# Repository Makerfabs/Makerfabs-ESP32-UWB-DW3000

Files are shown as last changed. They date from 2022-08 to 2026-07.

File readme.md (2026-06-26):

# Makerfabs ESP32 UWB DW3000

**The DW3000 library in this repository was developed by NConcepts, not Makerfabs.  Makerfabs is simply responsible for maintaining the repository.**

```c++
/*
Version:        V1.2
Author:            Vincent
Create Date:    2022/8/1
Note:
    2023/5/5     V1.2:The routines that can be used are placed in 
                    the example folder separately, with instructions 
                    added.
    2023/3/18    V1.1:Modify the SPI operating frequency in the library.
                      Added software reset to demo.
*/
```

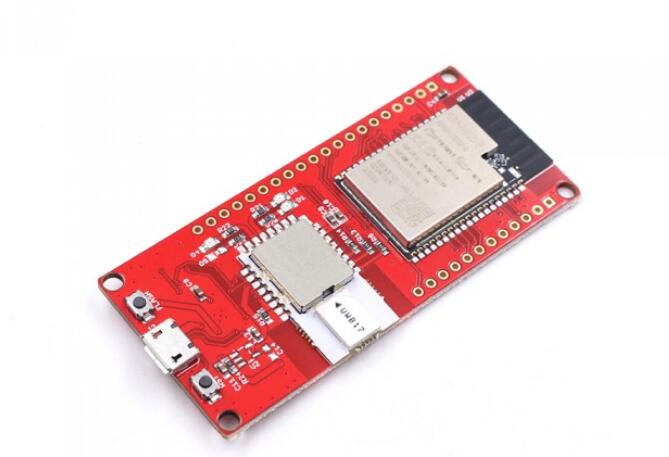
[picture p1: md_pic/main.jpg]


[TOC]

# Makerfabs

[Makerfabs home page](https://www.makerfabs.com/)

[Makerfabs Wiki](https://wiki.makerfabs.com/)

# Makerfabs ESP32 UWB DW3000

## 1.Intruduce

Click the image below to watch the demonstration on YouTube.

Watch the video (https://www.youtube.com/watch?v=JwxK1K1YVI8)

Product Link ：[esp32-uwb-dw3000](https://www.makerfabs.com/esp32-uwb-dw3000.html) 

Wiki Link : [ESP32 UWB DW3000](https://wiki.makerfabs.com/ESP32_DW3000_UWB.html)

Makerfabs ESP32 UWB contains an ESP32 and a DW3000 chip.

Ultra-wideband (UWB) is a short-range, wireless communication protocol that operates through radio waves, enables secure reliable ranging and precision sensing, creating a new dimension of spatial context for wireless devices.

Makerfabs ESP32 UWB module, which is based on IC DecaWave DW1000, has been greatly popular and liked by many Makers. And many customers ask us for the newest DW3000 version, after long-term comparison & testing, now it's available!~

Compares to the DWM1000, the DWM3000 has advantages as below:

1. Most important: Interoperable with Apple U1 chip, that makes it possible to work with the Apple system;
2. Fully aligned with FiRa™ PHY, MAC, and certification development, which make it more suitable for further applications;
3. Much lower Power consumption, almost 1/3 of DWM1000;
4. Supports UWB channels 5 (6.5 GHz) and 9 (8 GHz), while DWM1000 does not support Channel 9;

## 2.Feature

- Integrated ESP32 2.4G WiFi and Bluetooth.
- DW3000 UWB module.

# 3.Usage

ESP32 UWB DW3000 module ranging principle.

ESP32 UWB DW30003.jpg

ESP32 UWB DW30004.jpg

Download the DW3000 library in [GitHub](https://github.com/Makerfabs/Makerfabs-ESP32-UWB-DW3000/tree/main), and put it to the Arduino library file.

**Note: The DW3000 library in this repository was developed by NConcepts, not Makerfabs. Makerfabs is simply responsible for maintaining the repository.**

### 3.1 One Anchor + one Tag

**How to set ESP32 UWB DW3000 module as the anchor port.**

- Prepare the module and connect it to the PC with a USB cable.

- There is a sketch(range_tx.ino) for the setting, the sketch is available on [GitHub](https://github.com/Makerfabs/Makerfabs-ESP32-UWB-DW3000/tree/main). The path is >>example>>range_tx>>range_t.ino.

- Open the sketch with Arduino IDE. If you did not install the ESP32 development board on Arduino IDE, please check here for how to install it.
- Select the development board "ESP32 Dev Module" and the port.

ESP32 UWB DW30005.jpg

- Upload the sketch to the board.

- This module can be an anchor port to receive the other UWB device signal.

**How to use ESP32 UWB DW3000 module to measure the distance from the anchor port.**

How to use ESP32 UWB Pro module to measure the distance from the anchor port.

- Open the sketch **range_rx** by Arduino IDE. The path is >>example>>range_rx>>range_rx.ino
- As above mentioned to install the development board and library.
- Select the development board “ESP32 Dev Module” and the port.
- Upload the sketch to the board.
- Open the serial monitor, it will print the distance from the anchor port.

ESP32 UWB DW30007.jpg

ESP32 UWB DW30006.jpg

### 3.2 Multi Anchor + Multi Tag

This is the example to get the distance and signal strength value from multi Tag to multi Anchor.

The network uses a designated **Master Anchor** to coordinate synchronization and network scheduling.

``` 
#define MASTER_ANCHOR_ID    0xA0
```

The Master Anchor serves as the reference node for the entire UWB network and is responsible for:

- TDMA timing coordination
- Tag scheduling reference
- Maintaining a common network time base

All Anchors and Tags in the network must be configured with the same `MASTER_ANCHOR_ID`.

**Set the board to Anchor X or Tag X**

Open the [Tag](https://github.com/Makerfabs/Makerfabs-ESP32-UWB-DW3000/tree/main/example/Multi%20Anchor%20%2B%20Multi%20Tag/tag) and [Anchor](https://github.com/Makerfabs/Makerfabs-ESP32-UWB-DW3000/tree/main/example/Multi%20Anchor%20%2B%20Multi%20Tag/anchor) by Arduino IDE.

Modify code to get the Anchor or Tag that you want to define

``` 
// 0xA0~0xA7
#define MASTER_ANCHOR_ID    0xA0
```

``` 
//For example 0, 1, 2..
#define TAG_ID              0
```

Use Type-C USB cable to connect the board and PC, and select the development board "ESP32 Dev Module" and the port.

Verify the code and upload.

Repeat to set up multiple Anchor and multiple Tag.



Open the port for any anchor to view the distances from all tags to all anchors.



Results for 8Tag + 8anchor



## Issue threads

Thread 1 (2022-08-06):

Issue with TX example

roncapat, 2022-08-06:
Hello, I tried the code for the Simple TX example.
However, my code stalls in the while loop waiting for TX confirmation (checking TXFRS bit in SYS_STATUS reg). The bit is ever raised.
My SYS_STATUS register is the following:
00001001100000000000000000000111
Could you suggest if there are any other registers to check, particular flags or so?

I know it's not an issue directly related to your product, but your experience reaching production stage of a DWM3000-enabled board may help me a lot. Thank you in advance.

squix78, 2023-03-12:
I'm stuck at the same problem. Did you ever resolve it? I wonder if off-the-shelve DWM3000 are missing OTP calibration values

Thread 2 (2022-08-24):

ranging

c1p81, 2022-08-24:
when will be released the code for ranging tag-anchor (Arduino IDE)?
thanks
L

InfallibleProgrammer, 2022-09-11:
I have the same question

tomasrocchetti, 2023-02-07:
I have the same question, has anyone found a solution?

c1p81, 2023-02-07:
i'm testing this code
https://how2electronics.com/ranging-localization-with-esp32-uwb-dw3000-module/
seems to work...i need to find a way to calibrate the Antenna Delay

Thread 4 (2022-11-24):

Ranging using 9 channels

MitsuyoshiHori, 2022-11-24:
As We mentioned in my e-mail, when We changed the settings from 5ch to 9ch in the following sample, "CONFIG FAILED" due to "PLL LOCKING ERROR" occurred and it did not work properly.

[sample]
Dw3000\examples\ex_06a_ss_twr_initiator\ex_06a_ss_twr_initiator.ino
Dw3000\examples\ex_06b_ss_twr_responder\ex_06b_ss_twr_responder.ino

[Modified part]
static  dwt_config_t config = {
        5 , --（Changes） --> 9 ,

[operation log]
---------------------
Jun  8 2016 00:22:57

rst:0x1 (POWERON_RESET),boot:0x17 (SPI_FAST_FLASH_BOOT)
configsip: 0, SPIWP:0xee
clk_drv:0x00,q_drv:0x00,d_drv:0x00,cs0_drv:0x00,hd_drv:0x00,wp_drv:0x00
mode:DIO, clock div:1
load:0x3fff0030,len:1344
load:0x40078000,len:13864
load:0x40080400,len:3608
entry 0x400805f0
setup() run 9ch...
SS TWR INIT v1.0
DEVICE ID: deca0302
XTRIM OTP READ FAIL
PLL LOCKING ERROR
CONFIG FAILED
---------------------

However, as a result of putting the following serial output in the dw3000_device_api.cpp file, it works even with 9 channels, strangely enough.
We will share this information in the hope of further improvement.

---------------------
    ///////////////////////
    // RF
    if (chan == 9)
    {
        UART_puts("RF ch9 \r\n");   // Add for debug
        // Setup TX analog for ch9
        dwt_write32bitoffsetreg(TX_CTRL_HI_ID, 0, RF_TXCTRL_CH9);
        dwt_write16bitoffsetreg(PLL_CFG_ID, 0, RF_PLL_CFG_CH9);
        // Setup RX analog for ch9
        dwt_write32bitoffsetreg(RX_CTRL_HI_ID, 0, RF_RXCTRL_CH9);
    }
    else
    {
        UART_puts("RF ch5 \r\n");   // Add for debug
        // Setup TX analog for ch5
        dwt_write32bitoffsetreg(TX_CTRL_HI_ID, 0, RF_TXCTRL_CH5);

        dwt_write16bitoffsetreg(PLL_CFG_ID, 0, RF_PLL_CFG_CH5);

    }

    dwt_write8bitoffsetreg(LDO_RLOAD_ID, 1, LDO_RLOAD_VAL_B1);
    dwt_write8bitoffsetreg(TX_CTRL_LO_ID, 2, RF_TXCTRL_LO_B2);

    dwt_write8bitoffsetreg(PLL_CAL_ID, 0, RF_PLL_CFG_LD);        // Extend the lock delay

    //Verify PLL lock bit is cleared
    dwt_write32bitoffsetreg(SYS_STATUS_ID, 0, SYS_STATUS_CP_LOCK_BIT_MASK);

    ///////////////////////
    // auto cal the PLL and change to IDLE_PLL state
    dwt_setdwstate(DWT_DW_IDLE);

    for (flag=1,cnt=0;cnt<MAX_RETRIES_FOR_PLL;cnt++)
    {
       UART_puts("cnt:");         // Add for debug
       Serial.print(cnt, DEC);    // Add for debug
       UART_puts("\r\n");         // Add for debug
       //deca_usleep(DELAY_20uUSec);  /// comment-out
        if ((dwt_read8bitoffsetreg(SYS_STATUS_ID, 0) & SYS_STATUS_CP_LOCK_BIT_MASK))
        {//PLL is locked
      UART_puts("PLL is locked..");
      UART_puts("\r\n");
            flag=0;
            break;
        }
    }
---------------------

GGyul-E, 2024-11-08:
It's because the delay is not enough for PLL locking.
By printing UART Logs, it makes enough delay. So the most easy way is just using while loop for checking `SYS_STATUS_CP_LOCK_BIT_MASK` instead of using for loop.

`
/*for (flag=1,cnt=0;cnt<MAX_RETRIES_FOR_PLL;cnt++)
{
   //UART_puts("cnt:");         // Add for debug
   //Serial.print(cnt, DEC);    // Add for debug
   //UART_puts("\r\n");         // Add for debug
   deca_usleep(DELAY_100uUSec);  /// comment-out
    if ((dwt_read8bitoffsetreg(SYS_STATUS_ID, 0) & SYS_STATUS_CP_LOCK_BIT_MASK))
    {//PLL is locked
  //UART_puts("PLL is locked..");
  //UART_puts("\r\n");
        flag=0;
        break;
    }
}*/

while(dwt_read8bitoffsetreg(SYS_STATUS_ID, 0) & SYS_STATUS_CP_LOCK_BIT_MASK){
        UART_puts("PLL is locked..\r\n");
        flag = 0;
        break;
    }
`

MitsuyoshiHori, 2024-11-10:
Thanks for your comment.
I see, it is due to the lack of delay for the PLL lock.

I will try to find time to check SYS_STATUS_CP_LOCK_BIT_MASK using a while loop instead of a for loop.
As a side note, I have not tried this, but there was some information about another MAX_RETRIES_FOR_PLL setting that I would like to share.

https://forum.qorvo.com/t/esp32-uwb-dw3000-configuration-fails-for-ch9/12789

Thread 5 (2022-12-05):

Ranging Example

Harveyko, 2022-12-05:
Hello, sorry I am very new to this. I just got two https://www.makerfabs.com/esp32-uwb-dw3000.html from makerfabs. I try to use the example code provided on https://github.com/Makerfabs/Makerfabs-ESP32-UWB-DW3000 where I upload the initiator and responder code. I am confused on if the initiator is the anchor or tag, or which one should I kept stationary and which one should I move? Also may I ask is there any example on Antenna Delay Calibration, I found some resources for dw1000 but not dw3000. Thank you!

ThomasLengeling, 2022-12-07:
I have the same question, did you find a way to use the anchor-tags thanks!?

Harveyko, 2022-12-08:
Unfortunately not

vladvlasov256, 2023-04-03:
I had to fix the [example](https://how2electronics.com/ranging-localization-with-esp32-uwb-dw3000-module/) to make it work.

Tag:
```
#define POLL_TX_TO_RESP_RX_DLY_UUS 1720
#define RESP_RX_TIMEOUT_UUS 250
```

Anchor:
```
#define POLL_RX_TO_RESP_TX_DLY_UUS 2000
```

I used the constants from the AES examples [[1]](https://github.com/Makerfabs/Makerfabs-ESP32-UWB-DW3000/blob/3ea4cb14e4429012ae784a3543e146187acd3e09/Dw3000/examples/ex_06e_AES_ss_twr_initiator/ex_06e_AES_ss_twr_i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) and [[2]](https://github.com/Makerfabs/Makerfabs-ESP32-UWB-DW3000/blob/3ea4cb14e4429012ae784a3543e146187acd3e09/Dw3000/examples/ex_06f_AES_ss_twr_responder/ex_06f_AES_ss_twr_r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).

JerryIeong, 2023-04-04:
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

Thank you so much for your help! It works after correcting the values you mentioned!

Basically, what I did for DW3000 ESP32
1. I used "06a_ss_twr_initator" and "06a_ss_twr_responder"
2. change the related values of tag mentioned by Mr. vladvlasov256 (1720 and 250)
3. 2. change the related values of anchor mentioned by Mr. vladvlasov256 (2000)
4. Other content stays the same
5. Then it works

Again! Thank you for your helps!!

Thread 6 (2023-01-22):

UWB with Apple's Nearby Interaction example

Maxakipust, 2023-01-22:
I would love to see an example of Apple's Nearby Interaction working with one of these. Or having one interact with an air tag. Would this be possible?

zeevgrim, 2023-02-08:
+1

MaxIsMyName, 2023-03-09:
@Makerfabs , are you able to ask Qorvo or to port their libdwt_uwb_driver to allow the board to be used, as described on the product page, to interact with Apple's U1 chip?

goku-ks, 2023-04-25:
@Makerfabs, Unfortunately, the esp32 dw3000 is not compatible with this U1 chip if it is not possible to make it work with Apple devices. the claim that it is compatible with U1 chips is wrong.

it I only the Qorvo chip that is compatible with Apple U1 chips, but when it is combined with esp32, it is no more compatible with Apple U1 chips.

goku-ks, 2023-05-20:
@doublebyte , I had the same experience as @MaxIsMyName explained. This is a untrue claim by @Makerfabs that the board is compatible with U1 chips. May be the chip from Qorvo is, but in combination with ESP32 it is not as of now.

BhargavVadaliya, 2023-06-20:
@MaxIsMyName Do you have any news or information regarding the release date of Qorvo's SDK or Firmware for Xtensa chips?

robogrow, 2023-07-02:
Does anyone want to write some NI code for the ESP32?

We might be able to come up with some funding for it.

ivnlabs, 2023-07-02:
@robogrow, I want to write code for the ESP32 DW3000 well-documented code, making the DW3000 TAG connects with more than one ANCHORS and give a correct measurement between all the connected anchors, Does this count?

scinfu, 2023-12-24:
+1

maa-x, 2023-12-25:
For a much cheaper and better product, you can buy Qorvo's DMW3001CDK. It doesn't have WiFi, but you can just make the CDK sent updates over UART and connect an ESP to that.

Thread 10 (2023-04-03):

Double sided two-way ranging

JakobOvergaard, 2023-04-03:
Hi,
I'm currently doing my master thesis in computer science and I'm trying to create a system to test the accuracy of UWB ranging. \
I'm trying to perform double sided two-way ranging using the ESP32 Dw3000 from [makerfabs](https://www.makerfabs.com/esp32-uwb-dw3000.html). - Eventually the goal is to perform asymmetric DB TWR with multiple anchors. \
The code base is written in c++ inspired by QORVOS own example [code](https://www.qorvo.com/products/d/da007992) 'ds_twr_responder' and 'ds_twr_initiator'. \
I'm using the Arduino IDE and this library.

However I'm having some issues with the code, as the final message from the initator to the responder gives me an error, which I cannot decode.
When the responder polls for the final message it reads the system status register for errors, which includes checking the following subregisters: \

All RX error masks:

- SYS_STATUS_RXPHE
- SYS_STATUS_RXFCE
- SYS_STATUS_RXFSL
- SYS_STATUS_RXSTO
- SYS_STATUS_ARFE
- SYS_STATUS_CIAERR

User defined RX error masks:

- SYS_STATUS_RXFTO_BIT_MASK
- SYS_STATUS_RXPTO_BIT_MASK

and the RXFCG subregister.

Printing the system status register gives me the following output:
"131312" which is the decimal representation of the hex value 200F0 and the binary representation of 100000000011110000. \
I know it should be possible to decode which subregister the error is coming from, however I have a hard time figuring it out.\

The code for the intiator and responder is attached below.

Does anyone have any idea what the error could be and how to fix it?

Additionally, I'm very interested in getting in contact with anybody having experience with the ESP32 Dw3000 from makerfabs.

---

Initator code:

```c++
#include "dw3000.h"

#define APP_NAME "SS TWR INIT v1.0"

// connection pins
const uint8_t PIN_RST = 27; // reset pin
const uint8_t PIN_IRQ = 34; // irq pin
const uint8_t PIN_SS = 4;   // spi select pin

/* Default communication configuration. We use default non-STS DW mode. */
static dwt_config_t config = {
    5,                /* Channel number. */
    DWT_PLEN_128,     /* Preamble length. Used in TX only. */
    DWT_PAC8,         /* Preamble acquisition chunk size. Used in RX only. */
    9,                /* TX preamble code. Used in TX only. */
    9,                /* RX preamble code. Used in RX only. */
    1,                /* 0 to use standard 8 symbol SFD, 1 to use non-standard 8 symbol, 2 for non-standard 16 symbol SFD and 3 for 4z 8 symbol SDF type */
    DWT_BR_6M8,       /* Data rate. */
    DWT_PHRMODE_STD,  /* PHY header mode. */
    DWT_PHRRATE_STD,  /* PHY header rate. */
    (129 + 8 - 8),    /* SFD timeout (preamble length + 1 + SFD length - PAC size). Used in RX only. */
    DWT_STS_MODE_OFF, /* STS disabled */
    DWT_STS_LEN_64,   /* STS length see allowed values in Enum dwt_sts_lengths_e */
    DWT_PDOA_M0       /* PDOA mode off */
};

/* Inter-ranging delay period, in milliseconds. */
#define RNG_DELAY_MS 1000

/* Default antenna delay values for 64 MHz PRF. See NOTE 2 below. */
#define TX_ANT_DLY 16385
#define RX_ANT_DLY 16385

/* Frames used in the ranging process. See NOTE 3 below. */
static uint8_t tx_poll_msg[] = {0x41, 0x88, 0, 0xCA, 0xDE, 'C', 'C', 'D', 'D', 0x21, 0, 0};
static uint8_t rx_resp_msg[] = {0x41, 0x88, 0, 0xCA, 0xDE, 'D', 'D', 'C', 'C', 0x10, 0x02, 0, 0};
static uint8_t tx_final_msg[] = {0x41, 0x88, 0, 0xCA, 0xDE, 'C', 'C', 'D', 'D', 0x23, 0, 0, 0, 0, 0, 0, 0, 0, 0, 0, 0, 0, 0, 0};

/* Length of the common part of the message (up to and including the function code, see NOTE 3 below). */
#define ALL_MSG_COMMON_LEN 10
/* Indexes to access some of the fields in the frames defined above. */
#define ALL_MSG_SN_IDX 2
#define RESP_MSG_POLL_RX_TS_IDX 10
#define RESP_MSG_RESP_TX_TS_IDX 14
#define POLL_MSG_POLL_TX_TS_IDX 10

#define FINAL_MSG_POLL_TX_TS_IDX 10
#define FINAL_MSG_RESP_RX_TS_IDX 14
#define FINAL_MSG_FINAL_TX_TS_IDX 18

#define RESP_MSG_TS_LEN 4
/* Frame sequence number, incremented after each transmission. */
static uint8_t frame_seq_nb = 0;

/* Buffer to store received response message.
 * Its size is adjusted to longest frame that this example code is supposed to handle. */
#define RX_BUF_LEN 25
static uint8_t rx_buffer[RX_BUF_LEN];

/* Hold copy of status register state here for reference so that it can be examined at a debug breakpoint. */
static uint32_t status_reg = 0;
static uint32_t poll_tx_ts, resp_rx_ts;

/* Delay between frames, in UWB microseconds. See NOTE 1 below. */
#ifdef RPI_BUILD
#define POLL_TX_TO_RESP_RX_DLY_UUS 240
#endif // RPI_BUILD
#ifdef STM32F429xx
#define POLL_TX_TO_RESP_RX_DLY_UUS 240
#endif // STM32F429xx
#ifdef NRF52840_XXAA
#define POLL_TX_TO_RESP_RX_DLY_UUS 240
#endif // NRF52840_XXAA
/* Receive response timeout. See NOTE 5 below. */
#ifdef RPI_BUILD
#define RESP_RX_TIMEOUT_UUS 270
#endif // RPI_BUILD
#ifdef STM32F429xx
#define RESP_RX_TIMEOUT_UUS 210
#endif // STM32F429xx
#ifdef NRF52840_XXAA
#define RESP_RX_TIMEOUT_UUS 400
#endif // NRF52840_XXAA

#define POLL_TX_TO_RESP_RX_DLY_UUS 240
#define RESP_RX_TO_FINAL_TX_DLY_UUS 300
#define RESP_RX_TIMEOUT_UUS 400

/* Hold copies of computed time of flight and distance here for reference so that it can be examined at a debug breakpoint. */
static double tof, t_round_1, t_reply;
static double distance;

/* Values for the PG_DELAY and TX_POWER registers reflect the bandwidth and power of the spectrum at the current
 * temperature. These values can be calibrated prior to taking reference measurements. See NOTE 2 below. */
extern dwt_txconfig_t txconfig_options;

void setup()
{
  UART_init();
  test_run_info((unsigned char *)APP_NAME);
  Serial.begin(115200);

  /* Configure SPI rate, DW3000 supports up to 38 MHz */
  /* Reset DW IC */
  spiBegin(PIN_IRQ, PIN_RST);
  spiSelect(PIN_SS);

  delay(2); // Time needed for DW3000 to start up (transition from INIT_RC to IDLE_RC, or could wait for SPIRDY event)

  while (!dwt_checkidlerc()) // Need to make sure DW IC is in IDLE_RC before proceeding
  {
    UART_puts("IDLE FAILED\r\n");
    while (1)
      ;
  }

  if (dwt_initialise(DWT_DW_INIT) == DWT_ERROR)
  {
    UART_puts("INIT FAILED\r\n");
    while (1)
      ;
  }

  // Enabling LEDs here for debug so that for each TX the D1 LED will flash on DW3000 red eval-shield boards.
  dwt_setleds(DWT_LEDS_ENABLE | DWT_LEDS_INIT_BLINK);

  /* Configure DW IC. See NOTE 6 below. */
  if (dwt_configure(&config)) // if the dwt_configure returns DWT_ERROR either the PLL or RX calibration has failed the host should reset the device
  {
    UART_puts("CONFIG FAILED\r\n");
    while (1)
      ;
  }

  /* Configure the TX spectrum parameters (power, PG delay and PG count) */
  dwt_configuretxrf(&txconfig_options);

  /* Apply default antenna delay value. See NOTE 2 below. */
  dwt_setrxantennadelay(RX_ANT_DLY);
  dwt_settxantennadelay(TX_ANT_DLY);

  /* Set expected response's delay and timeout. See NOTE 1 and 5 below.
   * As this example only handles one incoming frame with always the same delay and timeout, those values can be set here once for all. */
  dwt_setrxaftertxdelay(POLL_TX_TO_RESP_RX_DLY_UUS);
  dwt_setrxtimeout(RESP_RX_TIMEOUT_UUS);

  /* Next can enable TX/RX states output on GPIOs 5 and 6 to help debug, and also TX/RX LEDs
   * Note, in real low power applications the LEDs should not be used. */
  dwt_setlnapamode(DWT_LNA_ENABLE | DWT_PA_ENABLE);
}

void loop()
{

  tx_poll_msg[ALL_MSG_SN_IDX] = frame_seq_nb;

  dwt_write32bitreg(SYS_STATUS_ID, SYS_STATUS_TXFRS_BIT_MASK);
  dwt_writetxdata(sizeof(tx_poll_msg), tx_poll_msg, 0); /* Zero offset in TX buffer. */
  dwt_writetxfctrl(sizeof(tx_poll_msg), 0, 1);          /* Zero offset in TX buffer, ranging. */

  /* Start transmission, indicating that a response is expected so that reception is enabled automatically after the frame is sent and the delay
   * set by dwt_setrxaftertxdelay() has elapsed. */
  dwt_starttx(DWT_START_TX_IMMEDIATE | DWT_RESPONSE_EXPECTED);

  /* We assume that the transmission is achieved correctly, poll for reception of a frame or error/timeout. See NOTE 8 below. */
  while (!((status_reg = dwt_read32bitreg(SYS_STATUS_ID)) & (SYS_STATUS_RXFCG_BIT_MASK | SYS_STATUS_ALL_RX_TO | SYS_STATUS_ALL_RX_ERR)))
  {
  };

  /* Increment frame sequence number after transmission of the poll message (modulo 256). */
  frame_seq_nb++;

  if (status_reg & SYS_STATUS_RXFCG_BIT_MASK)
  {
    uint32_t frame_len;

    /* Clear good RX frame event & TX frame sent in the DW IC status register. */
    dwt_write32bitreg(SYS_STATUS_ID, SYS_STATUS_RXFCG_BIT_MASK);
    dwt_write32bitreg(SYS_STATUS_ID, SYS_STATUS_TXFRS_BIT_MASK);

    /* A frame has been received, read it into the local buffer. */
    frame_len = dwt_read32bitreg(RX_FINFO_ID) & RXFLEN_MASK;
    if (frame_len <= sizeof(rx_buffer))
    {
      dwt_readrxdata(rx_buffer, frame_len, 0);
    }

    /* Check that the frame is the expected response from the companion "SS TWR responder" example.
     * As the sequence number field of the frame is not relevant, it is cleared to simplify the validation of the frame. */
    rx_buffer[ALL_MSG_SN_IDX] = 0;
    if (memcmp(rx_buffer, rx_resp_msg, ALL_MSG_COMMON_LEN) == 0)
    {

      uint32_t final_tx_ts, final_tx_time;
      int ret;
      float clockOffsetRatio;

      /* Retrieve poll transmission and response reception timestamps. See NOTE 9 below. */
      poll_tx_ts = dwt_readtxtimestamplo32();
      resp_rx_ts = dwt_readrxtimestamplo32();

      /* Read carrier integrator value and calculate clock offset ratio. See NOTE 11 below. */
      clockOffsetRatio = ((float)dwt_readclockoffset()) / (uint32_t)(1 << 26);

      /* Compute final message transmission time. See NOTE 7 below. */
      final_tx_time = (resp_rx_ts + (RESP_RX_TO_FINAL_TX_DLY_UUS * UUS_TO_DWT_TIME)) >> 8;
      dwt_setdelayedtrxtime(final_tx_time);

      /* final TX timestamp is the transmission time we programmed plus the antenna delay. */
      final_tx_ts = (((uint64_t)(final_tx_time & 0xFFFFFFFEUL)) << 8) + TX_ANT_DLY;

      /* Write resp_rx_ts & final_tx_ts in the final message. See NOTE 8 below. */
      final_msg_set_ts(&tx_final_msg[FINAL_MSG_POLL_TX_TS_IDX], poll_tx_ts);
      final_msg_set_ts(&tx_final_msg[FINAL_MSG_RESP_RX_TS_IDX], resp_rx_ts);
      final_msg_set_ts(&tx_final_msg[FINAL_MSG_FINAL_TX_TS_IDX], final_tx_ts);

      /* Write and send the response message. See NOTE 9 below. */
      tx_final_msg[ALL_MSG_SN_IDX] = frame_seq_nb;
      dwt_writetxdata(sizeof(tx_final_msg), tx_final_msg, 0); /* Zero offset in TX buffer. */
      dwt_writetxfctrl(sizeof(tx_final_msg), 0, 1);           /* Zero offset in TX buffer, ranging. */
      ret = dwt_starttx(DWT_START_TX_DELAYED);

      if (ret == DWT_SUCCESS)
      {
        test_run_info((unsigned char *)"Succes");
        /* Poll DW IC until TX frame sent event set. See NOTE 6 below. */
        while (!(dwt_read32bitreg(SYS_STATUS_ID) & SYS_STATUS_TXFRS_BIT_MASK))
        {
        };
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
MaxIsMyName, 2023-04-03:
You should probably read the DW3000’s datasheet.

lordxxbyron, 2023-04-12:
I am also interested in collaborating with a double sided two way ranging - you can PM me at lordxxbyron@gmail.com

Gurkengewuerz, 2024-01-17:
Hey @JakobOvergaard and @lordxxbyron did you ever succeeded with a working example?

JakobOvergaard, 2024-02-29:
@Gurkengewuerz Unfortunately not. I ended up doing singled sided two way ranging from one target to multiple anchors, which worked decently, however it had troubles estimating the position of fast moving targets accurately.

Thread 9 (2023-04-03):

The ESP32 DW3000 Pair is unable to Connect

JerryIeong, 2023-04-03:
Hi,

Let me thank in advance.

I am trying to connect two ESP32 DW3000 and to show the distance between two by using the sample code in arduino "ex_06a_ss_twr_initiator" and "ex_06a_ss_twr_responder".

However, the connection is not successful, once I embedded the programmes into the baords and open the serial monitor to see the result, the program just showed

- SS TWR INIT v1.0
- DEVICE ID: deca0302
- XTRIM OTP READ FAIL
- PLL is locked..
- PGF cal complete..

(The board name I used is ESP32 Wrover Modulus)

Did I miss something and can anyone help me out with this?

Thank you for your helps!

vladvlasov256, 2023-04-03:
@JerryIeong maybe this answer helps:
https://github.com/Makerfabs/Makerfabs-ESP32-UWB-DW3000/issues/5#issuecomment-1493962519

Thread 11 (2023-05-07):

Putting ESP32 DW3000 Pair into Sleep

JerryIeong, 2023-05-07:
Hi,

Let me thank in advance.

I have been working on DW3000 distance detection and warning system for few months and everything works fine, when the two UWB systems get too close, a pin will be triggered to activate an alarm.

I am currently using the "ex_06a_ss_twr_initator" and "ex_06a_ss_twr_responder" with Arduino for the system.

 After certain period of testing, I realized that the power consumption is quite high which may not be suitable for the system to be portable by carrying batteries. After reading through the manuals, I found out that there are different modes, like "sleep", "deep sleep" and "sniff mode", and there are also two "sleep" example programming in the Arduino.

Could anyone please instruct me how I can add these modes into my Arduino program for reducing power consumption?

Thank you for your helps!

MaxIsMyName, 2023-05-07:
You would have to read the datasheet for the DW3000 and send the correct command to enter and exit sleep or deep sleep.

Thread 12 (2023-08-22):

LEDSFD pin

LowellSeal, 2023-08-22:
Is there a way to make the LEDSFD pin go high to light LED D4 when a Start of Frame is Detected?  I don't see anything in the driver to do that but if someone has figured it out I'd sure appreciate knowing about it.

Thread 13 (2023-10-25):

When setting interrupts - i get an IllegalInstruction exception

ChristofGroschke, 2023-10-25:
Hi there,

I am currently using the dw3000 for a small university project. I am having a lot of problems enabling interrupts. One of them is that I can't call dwt_setInterrupts without the system rebooting due to an illegal instruction. I found out that the decamutexon function defined in dw3000_mutex.cpp should return a value, but it doesn't. The compiler warns me about this, but normally this shouldn't be a problem. If I return a value like NULL, the compilation is successful. Interrupts still don't work, but I'm not sure if that's related to this problem.

I have tried Ubuntu 22.04 with Arduino 1.8.19 and Windows 11 with Arduino 1.8.19 & 2.2.1 and neither works. Can anyone enlighten me on this?

Thanks in advance.

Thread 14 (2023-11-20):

How to set up the driver correctly for device ID DECA0314(DW3120)

AM0219350, 2023-11-20:
Hello,
I was implemented the TWR case with DWM3000 module. Now, I want to do the same thing on the ic DW3120 with single channel(one antenna) first. There are my problems below:

1. Is dw3000 api work on dw3120? The device id of dw3120 is deca0314. In the dw3000_device_api.h. Supported device are deca0302 and deca0312.
2. When I bypass the ckeck of device ID. I got failed in the procedure dwt_configure.
Check procedures:
---1. dwt_checkidlerc()
---2. dwt_initialise(DWT_DW_INIT) == DWT_ERROR
------ in the end of step 2. I got message "XTRIM OTP READ FAIL"
---3. dwt_configure(&config)
---4. Complete the above steps. ESP32 collapse.
3. How to set the dw3120 to use only one antenna?

Thanks,
Ken.

Screen shots:
1. ESP IDF
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
2. XIRIM OTP READ FAIL
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
3. Device IDs of the library(2013-2020)
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
4. Qorvo download library(2013-2021) new
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

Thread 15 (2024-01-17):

INIT FAILED

scinfu, 2024-01-17:
I have this problem with  example codes.
Anyone know why?
i'm using MaUWB_DW3000 with STM32 AT Command
SKU MAUWBCA1
https://www.makerfabs.com/mauwb-dw3000-with-stm32-at-command.html

```
....
12:35:25.674 -> [  1398][V][esp32-hal-periman.c:229] perimanSetBusDeinit(): Deinit function for type GPIO (1) successfully set to 0x400f52e8
12:35:25.674 -> [  1409][V][esp32-hal-periman.c:154] perimanSetPinBus(): Pin 4 successfully set to type GPIO (1) with bus 0x5
12:35:25.705 -> [  1423][V][esp32-hal-periman.c:229] perimanSetBusDeinit(): Deinit function for type GPIO (1) successfully set to 0x400f52e8
12:35:25.705 -> [  1434][V][esp32-hal-periman.c:154] perimanSetPinBus(): Pin 27 successfully set to type GPIO (1) with bus 0x1c
12:35:25.739 -> DEVICE ID: ffffffff

12:35:25.739 -> INIT FAILED
```

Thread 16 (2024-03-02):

MISO and MOSI are swapped

spectrachrome, 2024-03-02:
Running voltage measured on the DW3000 is ~2V until the two pins are swapped, then all SPI ports run 3.3V.

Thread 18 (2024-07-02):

XTRIM OTP READ FAIL

El-len000, 2024-07-02:
I tried the examples for the responder and initiator (e.g., ex_06b_ss_twr_responder_sts and ex_06e_AES_ss_twr_initiator), but I get the following error message:

XTRIM OTP READ FAIL

PLL is locked..
PGF cal complete..

I am new to using this device. I would really appreciate your help on how to resolve this error.

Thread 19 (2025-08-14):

Channel 9 not working

adijams01, 2025-08-14:
I am trying to use channel 9,  leds are not blinking and there is no output on the receiver's end of the serial print,
Can you please provide an example script for rx and tx using channel 9?
Thank you!

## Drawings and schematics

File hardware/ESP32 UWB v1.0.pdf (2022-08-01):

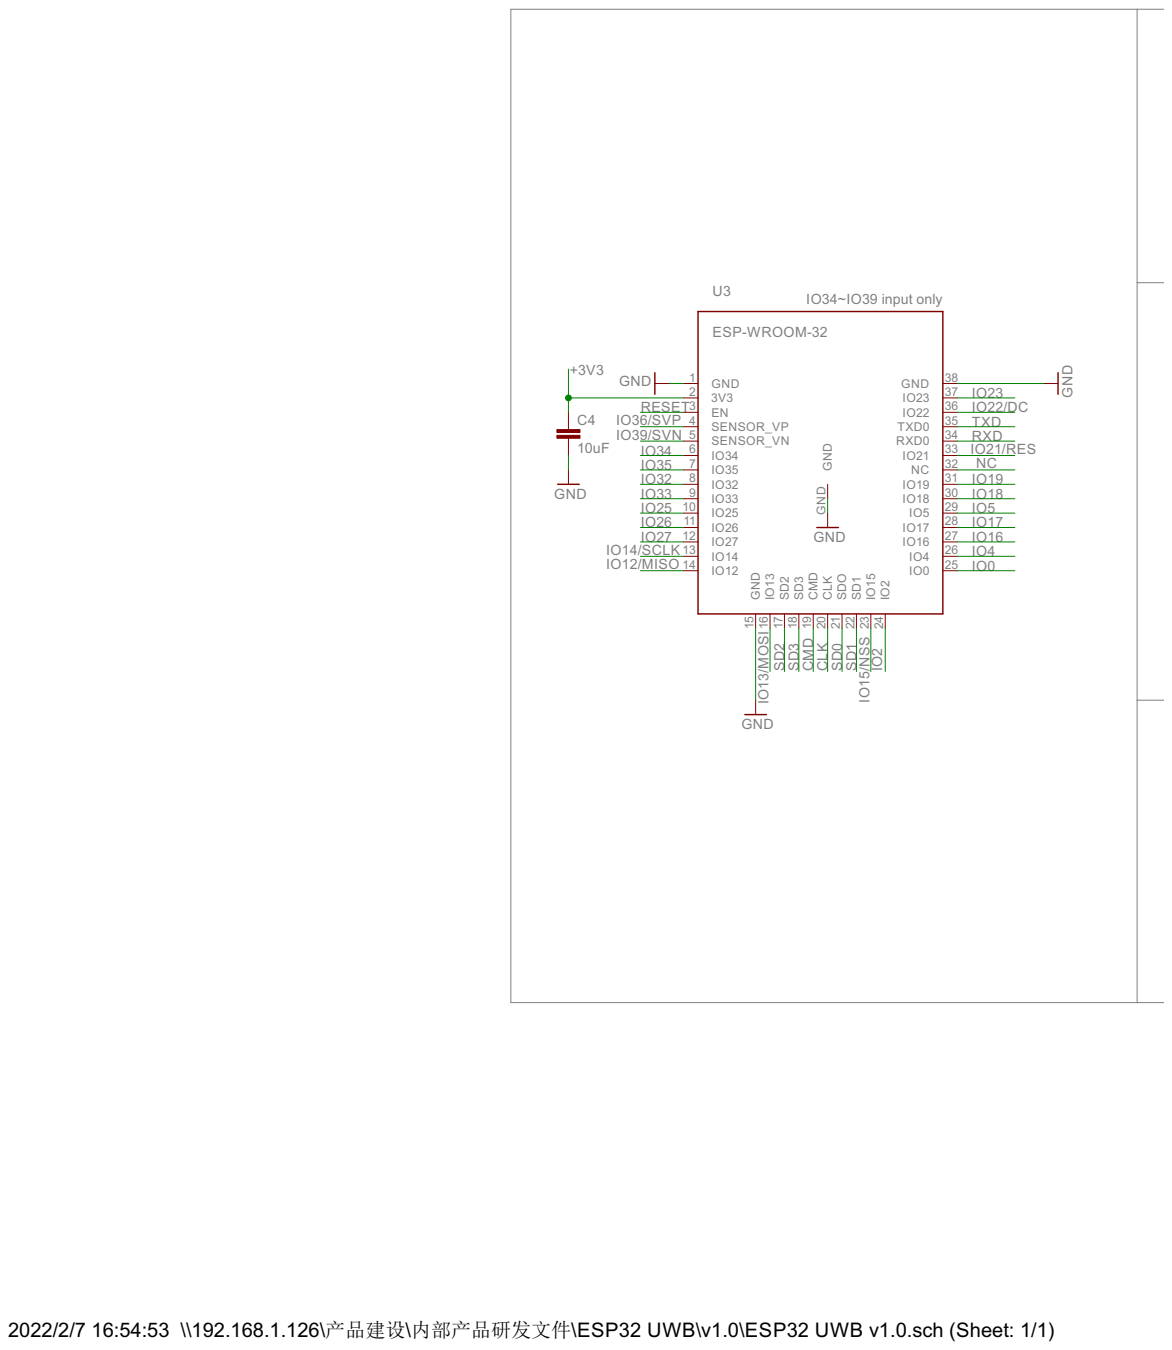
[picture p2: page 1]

2022/2/7 16:54:53 \\192.168.1.126\产品建设\内部产品研发文件\ESP32 UWB\v1.0\ESP32 UWB v1.0.sch (Sheet: 1/1)

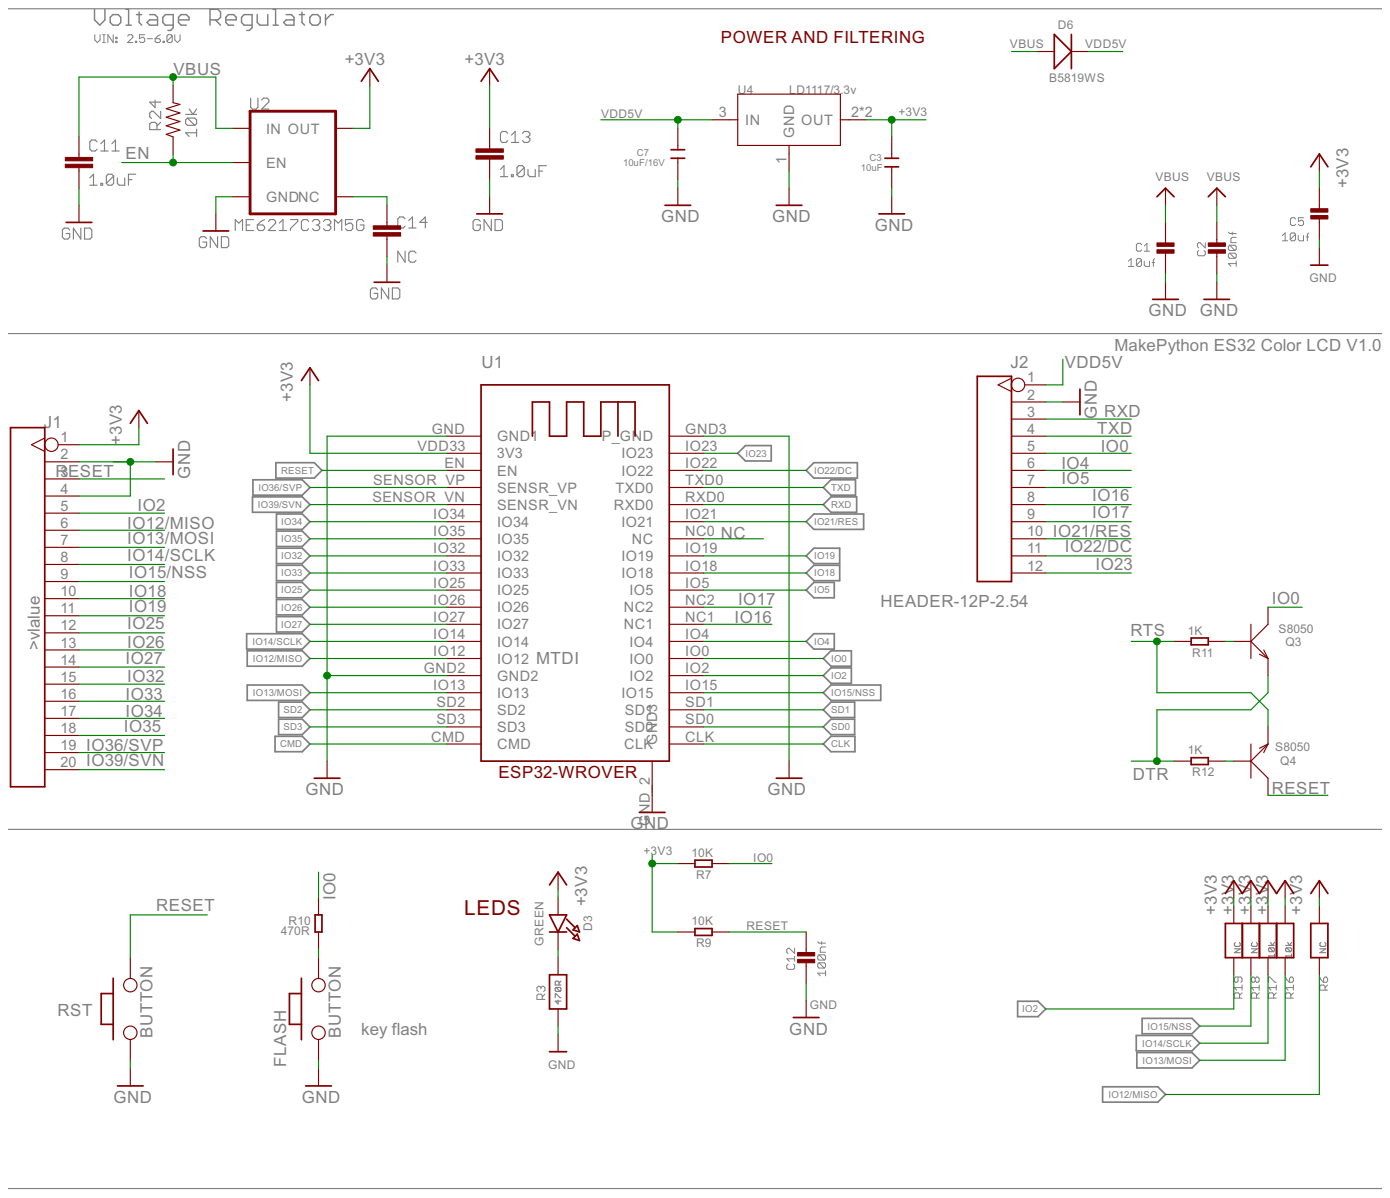
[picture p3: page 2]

IO25 | IO5
IO26 | IO17
IO27 | IO4 NC1 NC1 NC2 NC2 IO16

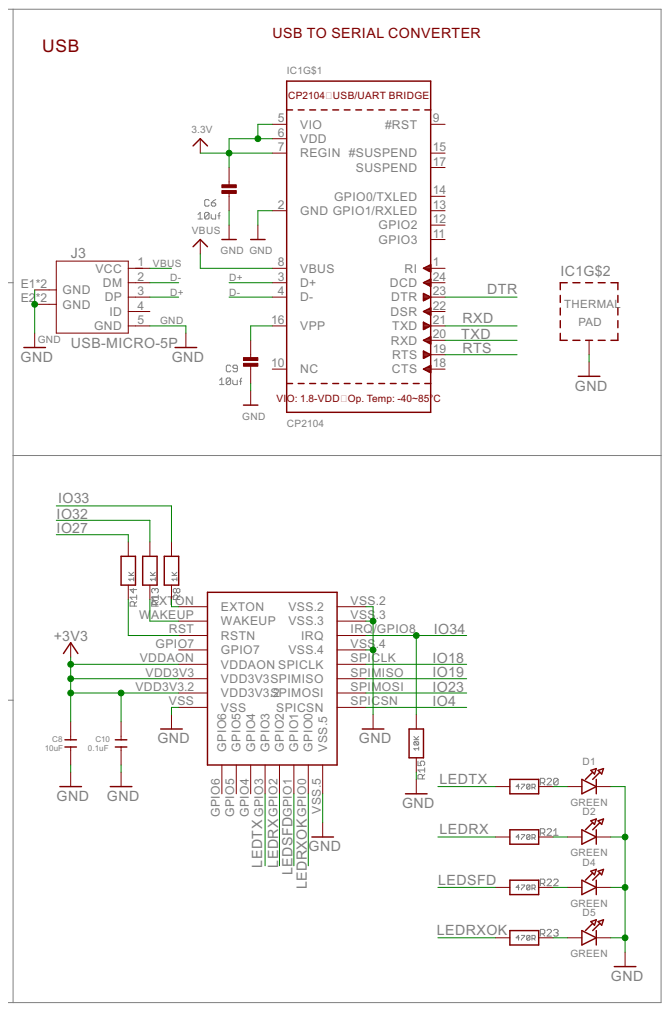
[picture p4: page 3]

USB TO SERIAL CONVERTER

VIO: 1.8-VDDOp. Temp: -40~85°C

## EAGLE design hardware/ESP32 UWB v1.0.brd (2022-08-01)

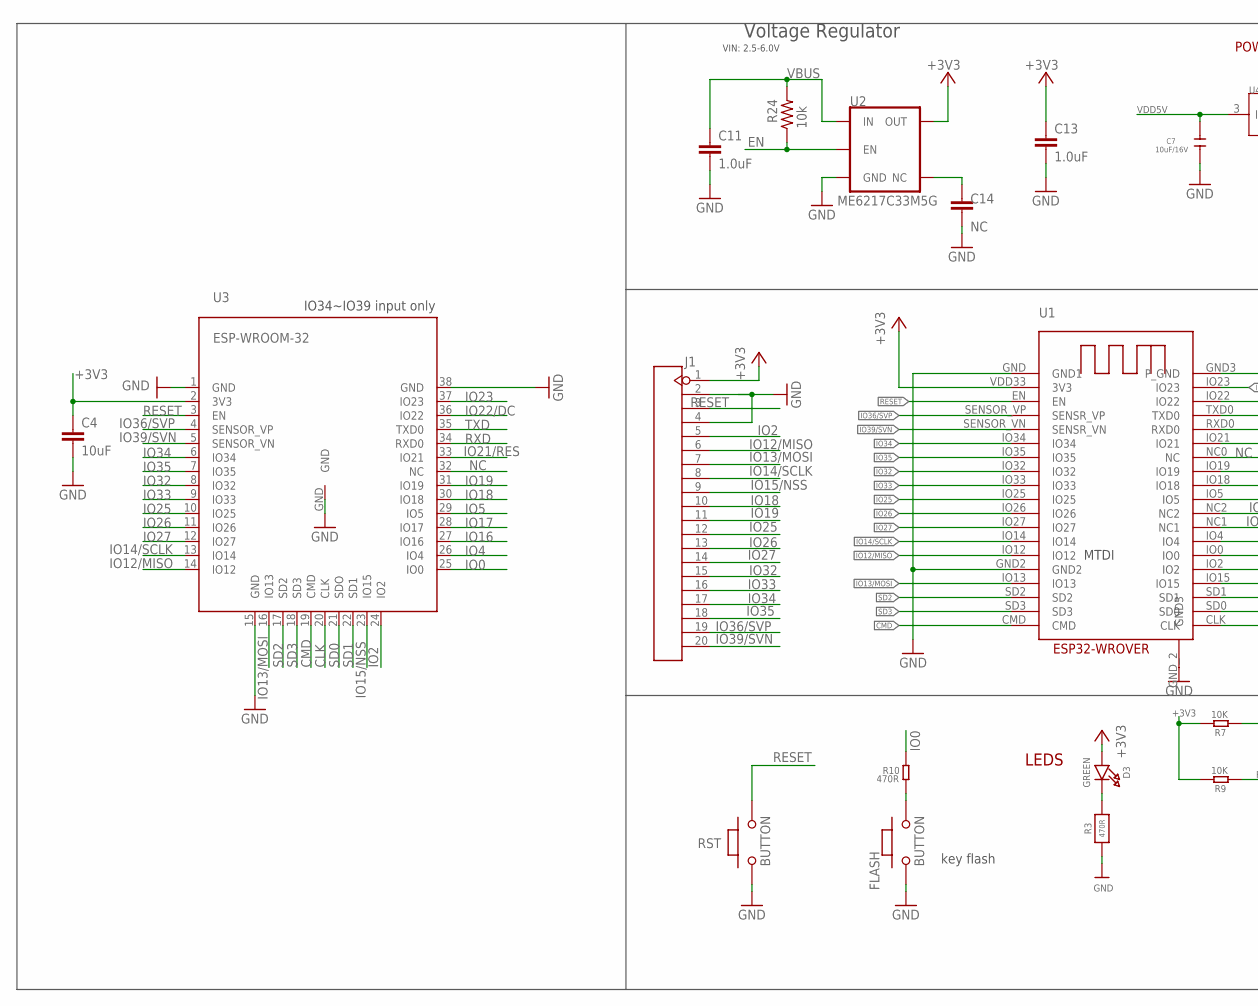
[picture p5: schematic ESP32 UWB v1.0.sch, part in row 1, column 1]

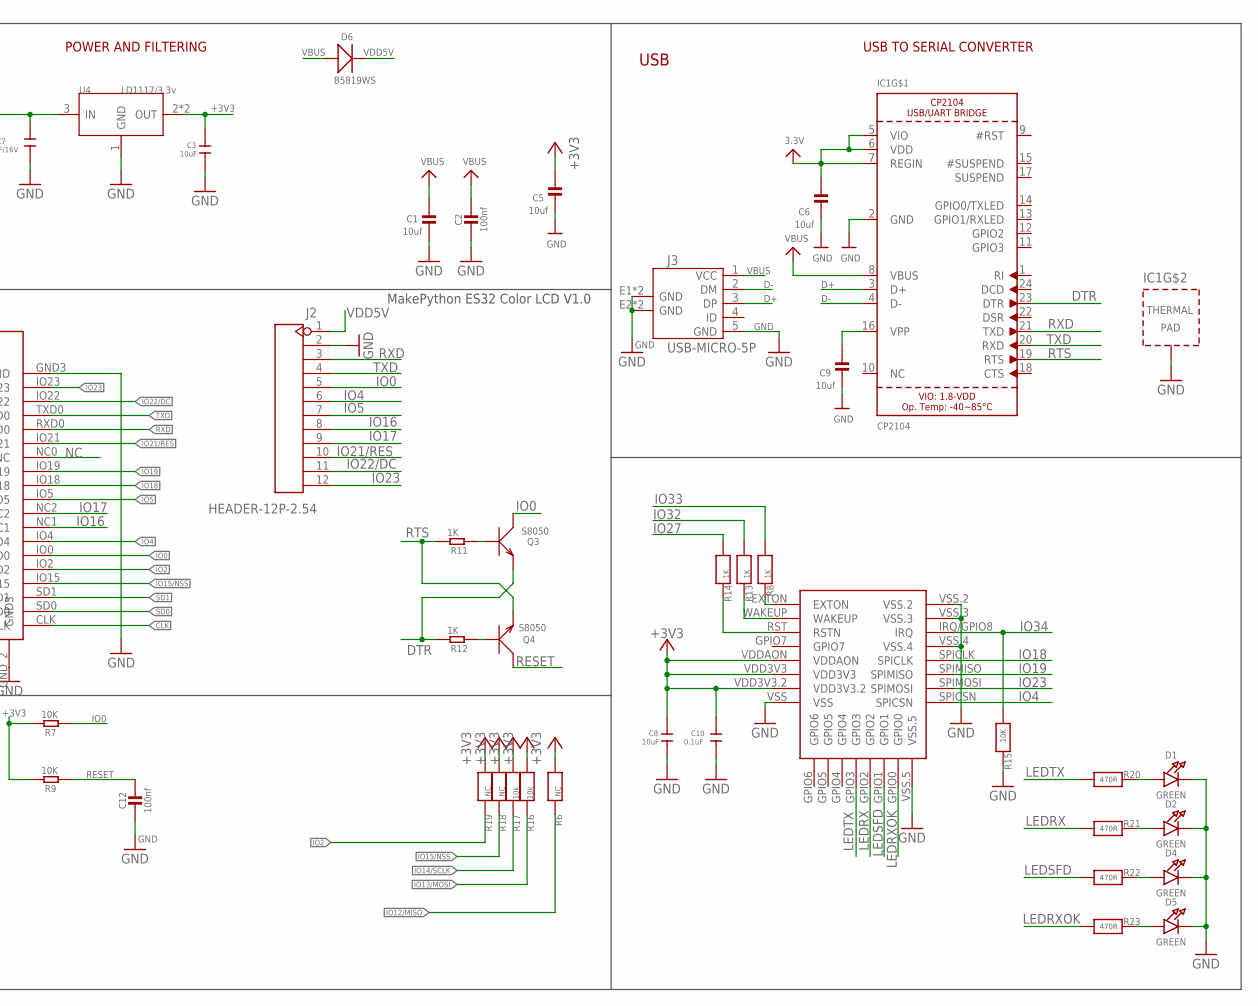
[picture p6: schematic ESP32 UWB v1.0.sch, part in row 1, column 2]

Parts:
C1, C5, C6, C9: 10uf; 0603-NO
C2, C12: 100nf; 0603-NO
C3, C4, C8: 10uF; C0603
C7: 10uF/16V; C0603
C10: 0.1uF; C0603
C11, C13: 1.0uF; 0603
C14: NC; 0603
D1, D2, D3, D4, D5: GREEN; CHIPLED_0805_NOOUTLINE
D6: B5819WS; SOD323
FLASH: BUTTON; 157SW
IC1: CP2104; QFN24_4MM_SMSC
J1: HEADER-20P-2.54; 20P-2.54
J2: HEADER-12P-2.54; 12P-2.54
J3: USB-MICRO-5P; MICRO-USB-5P
Q3, Q4: S8050; SOT23
R3, R20, R21, R22, R23: 470R; 0603-NO
R6, R18, R19: NC; 0603-NO
R7, R9: 10K; 0603
R8, R13, R14: 1K; 0603-NO
R10: 470R; 0603
R11, R12: 1K; 0603
R15: 10K; 0603-NO
R16, R17: 10k; 0603-NO
R24: 10k; 0603
RST: BUTTON; 157SW
U1: ESP32-WROVER
U2: ME6217C33M5G; SOT23-5
U3: ESP-WROOM-32
U4: LD1117/3.3v; SOT89
U5: DWM1000

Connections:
+3V3: C3.1, C4.1, C5.1, C6.1, C8.1, C10.1, C13.1, D3.A, IC1.5 (VIO), IC1.6 (VDD), IC1.7 (REGIN), J1.1, R6.1, R7.2, R9.2, R16.1, R17.1, R18.1, R19.1, U1.VDD33 (3V3), U2.5 (OUT), U3.2 (3V3), U4.2 (OUT), U4.4 (OUT), U5.VDD3V3, U5.VDD3V3.2, U5.VDDAON
CLK: U1.CLK, U3.20 (CLK)
CMD: U1.CMD, U3.19 (CMD)
D+: IC1.3 (D+), J3.3 (DP)
D-: IC1.4 (D-), J3.2 (DM)
DTR: IC1.23 (DTR), Q3.2 (E), R12.2
EN: R24.1, U2.3 (EN)
GND: C1.2, C2.2, C3.2, C4.2, C5.2, C6.2, C7.2, C8.2, C9.2, C10.2, C11.2, C12.2, C13.2, C14.2, D1.C, D2.C, D4.C, D5.C, FLASH.1, IC1.2 (GND), IC1.THERM (TP), J1.2, J1.4, J2.2, J3.5 (GND), J3.E1 (GND), J3.E2 (GND), J3.P1 (GND), J3.P2 (GND), R3.1, R15.2, RST.1, U1.GND (GND1), U1.GND2, U1.GND3 (P_GND), U1.GND_2 (GND3), U2.2 (GND), U3.1 (GND), U3.15 (GND), U3.38 (GND), U3.GND, U4.1 (GND), U5.VSS, U5.VSS.2, U5.VSS.3, U5.VSS.4, U5.VSS.5
IO0: J2.5, Q3.3 (C), R7.1, R10.2, U1.IO0, U3.25 (IO0)
IO2: J1.5, R19.2, U1.IO2, U3.24 (IO2)
IO4: J2.6, U1.IO4, U3.26 (IO4), U5.SPICSN
IO5: J2.7, U1.IO5, U3.29 (IO5)
IO12/MISO: J1.6, R6.2, U1.IO12, U3.14 (IO12)
IO13/MOSI: J1.7, R16.2, U1.IO13, U3.16 (IO13)
IO14/SCLK: J1.8, R17.2, U1.IO14, U3.13 (IO14)
IO15/NSS: J1.9, R18.2, U1.IO15, U3.23 (IO15)
IO16: J2.8, U1.NC1, U3.27 (IO16)
IO17: J2.9, U1.NC2, U3.28 (IO17)
IO18: J1.10, U1.IO18, U3.30 (IO18), U5.SPICLK
IO19: J1.11, U1.IO19, U3.31 (IO19), U5.SPIMISO
IO21/RES: J2.10, U1.IO21, U3.33 (IO21)
IO22/DC: J2.11, U1.IO22, U3.36 (IO22)
IO23: J2.12, U1.IO23, U3.37 (IO23), U5.SPIMOSI
IO25: J1.12, U1.IO25, U3.10 (IO25)
IO26: J1.13, U1.IO26, U3.11 (IO26)
IO27: J1.14, R14.1, U1.IO27, U3.12 (IO27)
IO32: J1.15, R13.1, U1.IO32, U3.8 (IO32)
IO33: J1.16, R8.1, U1.IO33, U3.9 (IO33)
IO34: J1.17, R15.1, U1.IO34, U3.6 (IO34), U5.IRQ/GPIO8 (IRQ)
IO35: J1.18, U1.IO35, U3.7 (IO35)
IO36/SVP: J1.19, U1.SENSOR_VP (SENSR_VP), U3.4 (SENSOR_VP)
IO39/SVN: J1.20, U1.SENSOR_VN (SENSR_VN), U3.5 (SENSOR_VN)
LEDRX: R21.1, U5.GPIO2
LEDRXOK: R23.1, U5.GPIO0
LEDSFD: R22.1, U5.GPIO1
LEDTX: R20.1, U5.GPIO3
unnamed: D1.A, R20.2
unnamed: C9.1, IC1.16 (VPP)
unnamed: C14.1, U2.4 (NC)
unnamed: D3.C, R3.2
unnamed: R8.2, U5.EXTON
unnamed: R13.2, U5.WAKEUP
unnamed: R14.2, U5.RST (RSTN)
unnamed: Q4.1 (B), R12.1
unnamed: Q3.1 (B), R11.1
unnamed: FLASH.2, R10.1
unnamed: D2.A, R21.2
unnamed: D4.A, R22.2
unnamed: D5.A, R23.2
NC: U1.NC0 (NC), U3.32 (NC)
RESET: C12.1, J1.3, Q4.3 (C), R9.1, RST.2, U1.EN, U3.3 (EN)
RTS: IC1.19 (RTS), Q4.2 (E), R11.2
RXD: IC1.21 (TXD), J2.3, U1.RXD0, U3.34 (RXD0)
SD0: U1.SD0, U3.21 (SDO)
SD1: U1.SD1, U3.22 (SD1)
SD2: U1.SD2, U3.17 (SD2)
SD3: U1.SD3, U3.18 (SD3)
TXD: IC1.20 (RXD), J2.4, U1.TXD0, U3.35 (TXD0)
VBUS: C1.1, C2.1, C11.1, D6.+, IC1.8 (VBUS), J3.1 (VCC), R24.2, U2.1 (IN)
VDD5V: C7.1, D6.-, J2.1, U4.3 (IN)

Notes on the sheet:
USB
LEDS
POWER AND FILTERING
USB TO SERIAL CONVERTER
key flash
MakePython ES32 Color LCD V1.0
MTDI
IO34~IO39 input only
Voltage Regulator
VIN: 2.5-6.0V

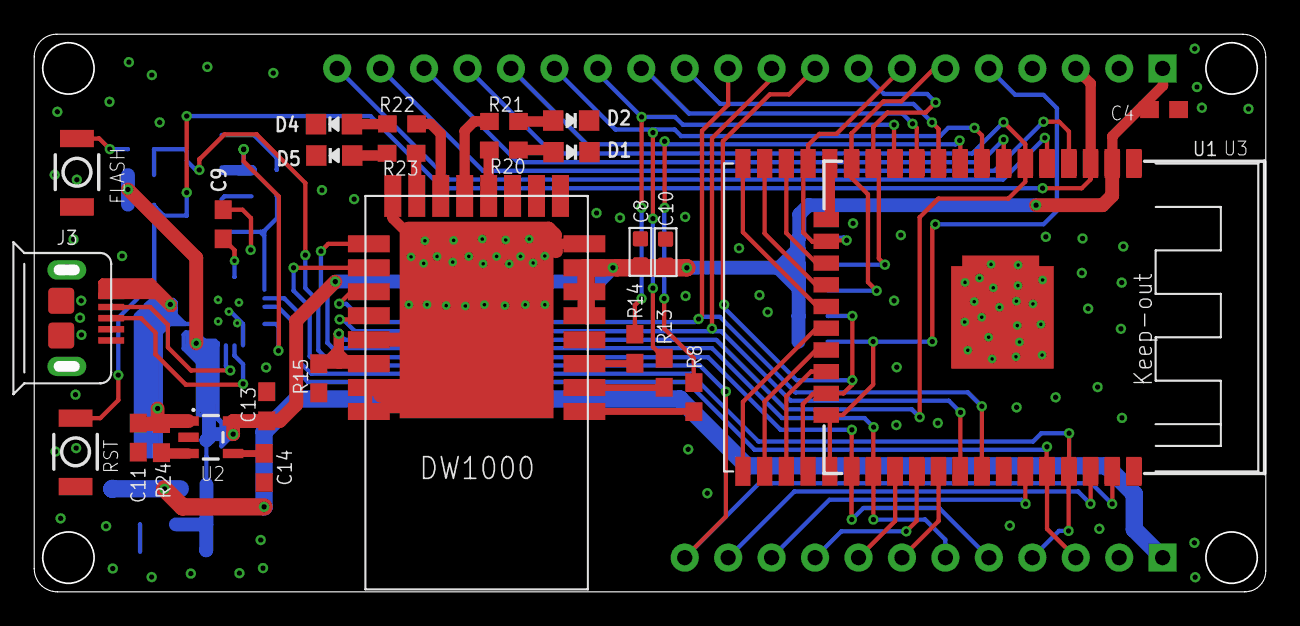
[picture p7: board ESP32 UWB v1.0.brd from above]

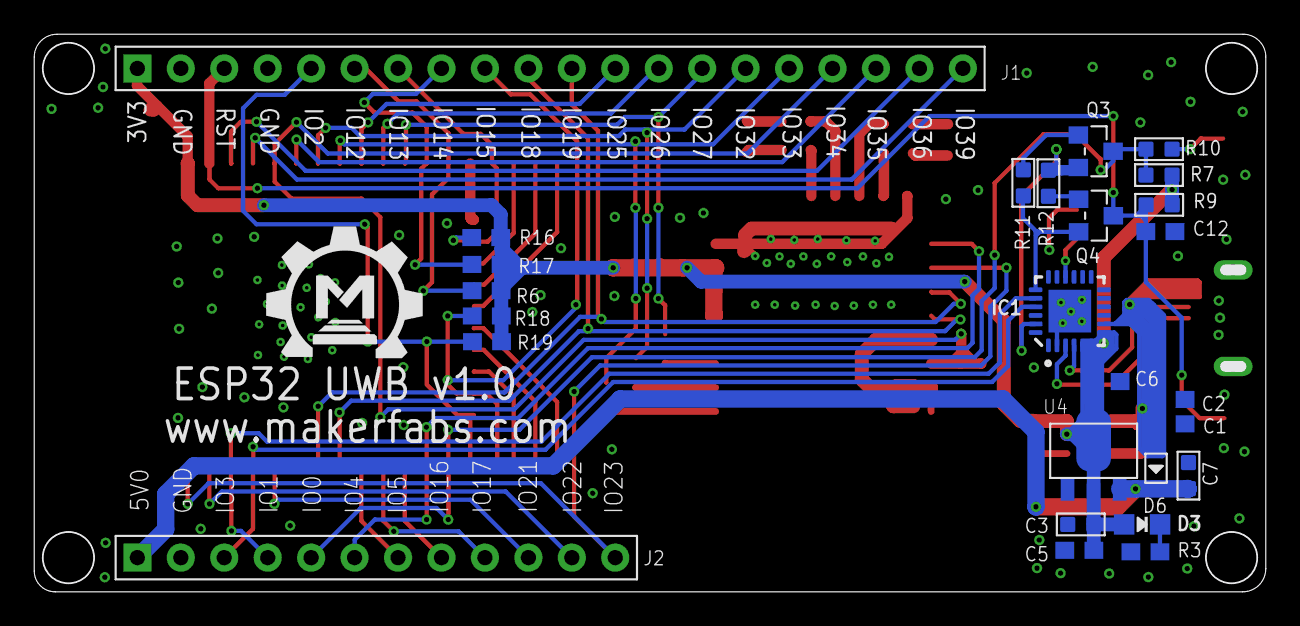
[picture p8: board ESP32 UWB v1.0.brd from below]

Board: 2 copper layers, 72.0 x 32.6 mm, 54 parts (27 on the bottom side), 60 nets.

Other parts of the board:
U$1: MAKERFABS_0.3

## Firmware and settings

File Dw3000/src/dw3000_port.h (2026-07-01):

/*
 * port.h
 *
 * Created: 9/10/2021 1:20:00 PM
 *  Author: Emin Eminof
 */ 

#ifndef PORT_H_
#define PORT_H_

#include "dw3000_board_config.h"
#include "dw3000.h"

#define DDR_SPI DDRB
#define DD_SCK DDB5
#define DD_MISO DDB4
#define DD_MOSI DDB3
#define DD_SS 4

#define DEFAULT_IRQ DW3000_PIN_IRQ
#define DEFAULT_RST DW3000_PIN_RST
#define DEFAULT_SS DW3000_PIN_CS

//#define DDR_PORTD DDRD
#define DD_RESET_PIN DW3000_PIN_RST

#ifndef FALSE
#define FALSE  0
#endif

#ifndef TRUE
#define TRUE  1
#endif

// PMSC
#define PMSC 0x36
#define PMSC_CTRL0_SUB 0x00
#define PMSC_CTRL1_SUB 0x04
#define PMSC_LEDC_SUB 0x28
#define LEN_PMSC_CTRL0 4
#define LEN_PMSC_CTRL1 4
#define LEN_PMSC_LEDC 4
#define GPDCE_BIT 18
#define KHZCLKEN_BIT 23
#define BLNKEN 8

#define ATXSLP_BIT 11
#define ARXSLP_BIT 12

// used for SPI ready w/o actual writes
#define JUNK 0x00

// no sub-address for register write
#define NO_SUB 0xFF

#define WRITE      0x80
#define WRITE_SUB  0xC0
#define READ       0x00
#define READ_SUB   0x40
#define RW_SUB_EXT 0x80

// device control register
#define SYS_CTRL 0x0D
#define LEN_SYS_CTRL 4
#define SFCST_BIT 0
#define TXSTRT_BIT 1
#define TXDLYS_BIT 2
#define TRXOFF_BIT 6
#define WAIT4RESP_BIT 7
#define RXENAB_BIT 8
#define RXDLYS_BIT 9

// device configuration register
#define SYS_CFG 0x04
#define LEN_SYS_CFG 4
#define FFEN_BIT 0
#define FFBC_BIT 1
#define FFAB_BIT 2
#define FFAD_BIT 3
#define FFAA_BIT 4
#define FFAM_BIT 5
#define FFAR_BIT 6
#define DIS_DRXB_BIT 12
#define DIS_STXP_BIT 18
#define HIRQ_POL_BIT 9
#define RXAUTR_BIT 29
#define PHR_MODE_SUB 16
#define LEN_PHR_MODE_SUB 2
#define RXM110K_BIT 22

// system event status register
#define SYS_STATUS 0x0F
#define LEN_SYS_STATUS 5
#define CPLOCK_BIT 1
#define AAT_BIT 3
#define TXFRB_BIT 4
#define TXPRS_BIT 5
#define TXPHS_BIT 6
#define TXFRS_BIT 7
#define LDEDONE_BIT 10
#define RXPHE_BIT 12
#define RXDFR_BIT 13
#define RXFCG_BIT 14
#define RXFCE_BIT 15
#define RXRFSL_BIT 16
#define RXRFTO_BIT 17
#define RXPTO_BIT 21
#define RXSFDTO_BIT 26
#define LDEERR_BIT 18
#define RFPLL_LL_BIT 24
#define CLKPLL_LL_BIT 25

// transmit control
#define TX_FCTRL 0x08
#define LEN_TX_FCTRL 5

// channel control
#define CHAN_CTRL 0x1F
#define LEN_CHAN_CTRL 4
#define DWSFD_BIT 17
#define TNSSFD_BIT 20
#define RNSSFD_BIT 21

// system event mask register
// NOTE: uses the bit definitions of SYS_STATUS (below 32)
#define SYS_MASK 0x0E
#define LEN_SYS_MASK 4
  
  /* clocks available. */
#define AUTO_CLOCK 0x00
#define XTI_CLOCK  0x01
#define PLL_CLOCK  0x02

// OTP control (for LDE micro code loading only)
#define OTP_IF 0x2D
#define OTP_ADDR_SUB 0x04
#define OTP_CTRL_SUB 0x06
#define OTP_RDAT_SUB 0x0A
#define LEN_OTP_ADDR 2
#define LEN_OTP_CTRL 2
#define LEN_OTP_RDAT 4

// enum to determine RX or TX mode of device
#define IDLE_MODE 0x00
#define RX_MODE 0x01
#define TX_MODE 0x02

// PAN identifier, short address register
#define PANADR 0x03
#define LEN_PANADR 4

void readBytes(byte cmd, uint16_t offset, byte data[], uint16_t n);
void readSystemEventStatusRegister();
void readSystemConfigurationRegister();
void writeSystemConfigurationRegister();
void readNetworkIdAndDeviceAddress();
void writeNetworkIdAndDeviceAddress();
void readSystemEventMaskRegister();
void writeSystemEventMaskRegister();
void readChannelControlRegister();
void writeChannelControlRegister();
void readTransmitFrameControlRegister();
void writeTransmitFrameControlRegister();
void setDoubleBuffering(boolean val);
void setBit(byte data[], uint16_t n, uint16_t bit, boolean val);
boolean getBit(byte data[], uint16_t n, uint16_t bit);
void writeValueToBytes(byte data[], int32_t val, uint16_t n);
void writeBytes(byte cmd, uint16_t offset, byte data[], uint16_t data_size);
void writeByte(byte cmd, uint16_t offset, byte data);
void reset();
void softReset();
void idle();
void spiBegin(uint8_t irq, uint8_t rst);
void spiSelect(uint8_t ss);
void enableClock(byte clock);
int writetospi(uint16_t headerLength,  uint8_t *headerBuffer, uint16_t bodyLength, uint8_t *bodyBuffer);
int readfromspi(uint16_t headerLength, uint8_t *headerBuffer, uint16_t readLength, uint8_t *readBuffer);

void Sleep(uint32_t d);
void enableDebounceClock();
void wakeup_device_with_io();

void port_set_dw_ic_spi_fastrate(uint8_t irq = DEFAULT_IRQ, uint8_t rst = DEFAULT_RST, uint8_t ss = DEFAULT_SS);

uint32_t port_GetEXT_IRQStatus(void);
uint32_t port_CheckEXT_IRQ(void);
void port_DisableEXT_IRQ(void);
void port_EnableEXT_IRQ(void);

/* DW IC IRQ (EXTI15_10_IRQ) handler type. */
typedef void (*port_dwic_isr_t)(void);

/*! ------------------------------------------------------------------------------------------------------------------
 * @fn port_set_DWIC_isr()
 *
 * @brief This function is used to install the handling function for DW1000 IRQ.
 *
 * NOTE:
 *   - As EXTI9_5_IRQHandler does not check that port_deca_isr is not null, the user application must ensure that a
 *     proper handler is set by calling this function before any DW1000 IRQ occurs!
 *   - This function makes sure the DW1000 IRQ line is deactivated while the handler is installed.
 *
 * @param deca_isr function pointer to DW1000 interrupt handler to install
 *
 * @return none
 */
void port_set_dwic_isr(port_dwic_isr_t isr);

#if 0
void sleepms(uint32_t x);
int sleepus(uint32_t x);
void deca_sleep(uint8_t time_ms);
void deca_usleep(uint8_t time_us);
void open_spi(void);
void close_spi(void);


void port_set_dw_ic_spi_slowrate(void);
void port_set_dw_ic_spi_fastrate(void);
void reset_DWIC(void);
int spi_tranceiver (uint8_t *data);
#endif

#endif /* PORT_H_ */

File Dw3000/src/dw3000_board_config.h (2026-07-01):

/*
 * Board defaults for the DW3000 Arduino port.
 *
 * Define any DW3000_PIN_* macro before including dw3000.h, or pass it as a
 * compiler flag, to override these defaults for a custom board.
 */

#ifndef DW3000_BOARD_CONFIG_H_
#define DW3000_BOARD_CONFIG_H_

#if defined(ARDUINO_ARCH_NRF52)

#ifndef DW3000_PIN_RST
#define DW3000_PIN_RST 14
#endif

#ifndef DW3000_PIN_IRQ
#define DW3000_PIN_IRQ 12
#endif

#ifndef DW3000_PIN_CS
#define DW3000_PIN_CS 7
#endif

#ifndef DW3000_PIN_SCK
#define DW3000_PIN_SCK 5
#endif

#ifndef DW3000_PIN_MOSI
#define DW3000_PIN_MOSI 9
#endif

#ifndef DW3000_PIN_MISO
#define DW3000_PIN_MISO 10
#endif

#else

#ifndef DW3000_PIN_RST
#define DW3000_PIN_RST 27
#endif

#ifndef DW3000_PIN_IRQ
#define DW3000_PIN_IRQ 34
#endif

#ifndef DW3000_PIN_CS
#define DW3000_PIN_CS 4
#endif

#endif

#endif /* DW3000_BOARD_CONFIG_H_ */

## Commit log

2023-03-18 V1.1 Fix SPI frequence
    [dw3000_port.cpp, ex_01a_simple_tx.ino, ex_02a_simple_rx.ino]
2023-05-05 Fix SPI frequence
2026-06-17 Fixed a bug where data update times were inconsistent
    [range_rx.ino, range_tx.ino]
2026-06-17 Fix the bug causing slow startup times
    [range_rx.ino, range_tx.ino]

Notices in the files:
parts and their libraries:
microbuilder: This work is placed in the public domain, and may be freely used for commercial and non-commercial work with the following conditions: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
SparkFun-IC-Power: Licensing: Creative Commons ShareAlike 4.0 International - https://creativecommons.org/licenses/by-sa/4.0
